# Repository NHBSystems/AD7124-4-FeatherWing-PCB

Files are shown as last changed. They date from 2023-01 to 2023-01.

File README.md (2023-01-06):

# AD7124-4 24bit Analog Sensor FeatherWing Design Files

This is a new Feather compatible board for reading precision analog sensors like load cells, thermocouples, and strain gauges. It uses the AD7124-4, a 4 channel, 24 bit, differential ADC (Can also be configured as 7 single ended channels). Like the [6 Channel 24 bit Featherwing](https://github.com/NHBSystems/6Ch-24bit-FeatherWing-PCB) this board is designed for lower power, monitoring type applications, however it can also be configured for significantly higher sampling rates than the AD7794. The board also includes a low pass anti-aliasing filter on the inputs, a 5th input pin for a shield wire connection, and software enabled excitation voltage without using an additional pin.

**Specifications**

- RMS noise down to 23 nV at 9.4 SPS
- Low power operation with 3 conversion power modes
- Power-down current of 5 μA maximum (AD7124 chip)
- Low noise, programmable gain instrumentation amplifier (1 to 128)
- Band gap reference with 10 ppm/°C drift typical
- Simultaneous 50 Hz/60 Hz rejection at 25 SPS
- Update rate: Up to 19200 sps (per datasheet for single channel)
- 4 differential analog inputs, (or 7 single ended)
- Independent configuration of each channel
- Low pass anti-aliasing filter on inputs
- 5 pin connections with excitation, ground, and shield for each channel
- Shield can be tied to chassis or to ground (trace jumper on bottom)
- On board 2.5v LDO controlled in software without needing additional pin
- Software enabled bias voltage on all channels (for reading thermocouples)

This board can be purchased assembled here: [24 bit Analog Sensor FeatherWing](https://www.tindie.com/products/24680/)



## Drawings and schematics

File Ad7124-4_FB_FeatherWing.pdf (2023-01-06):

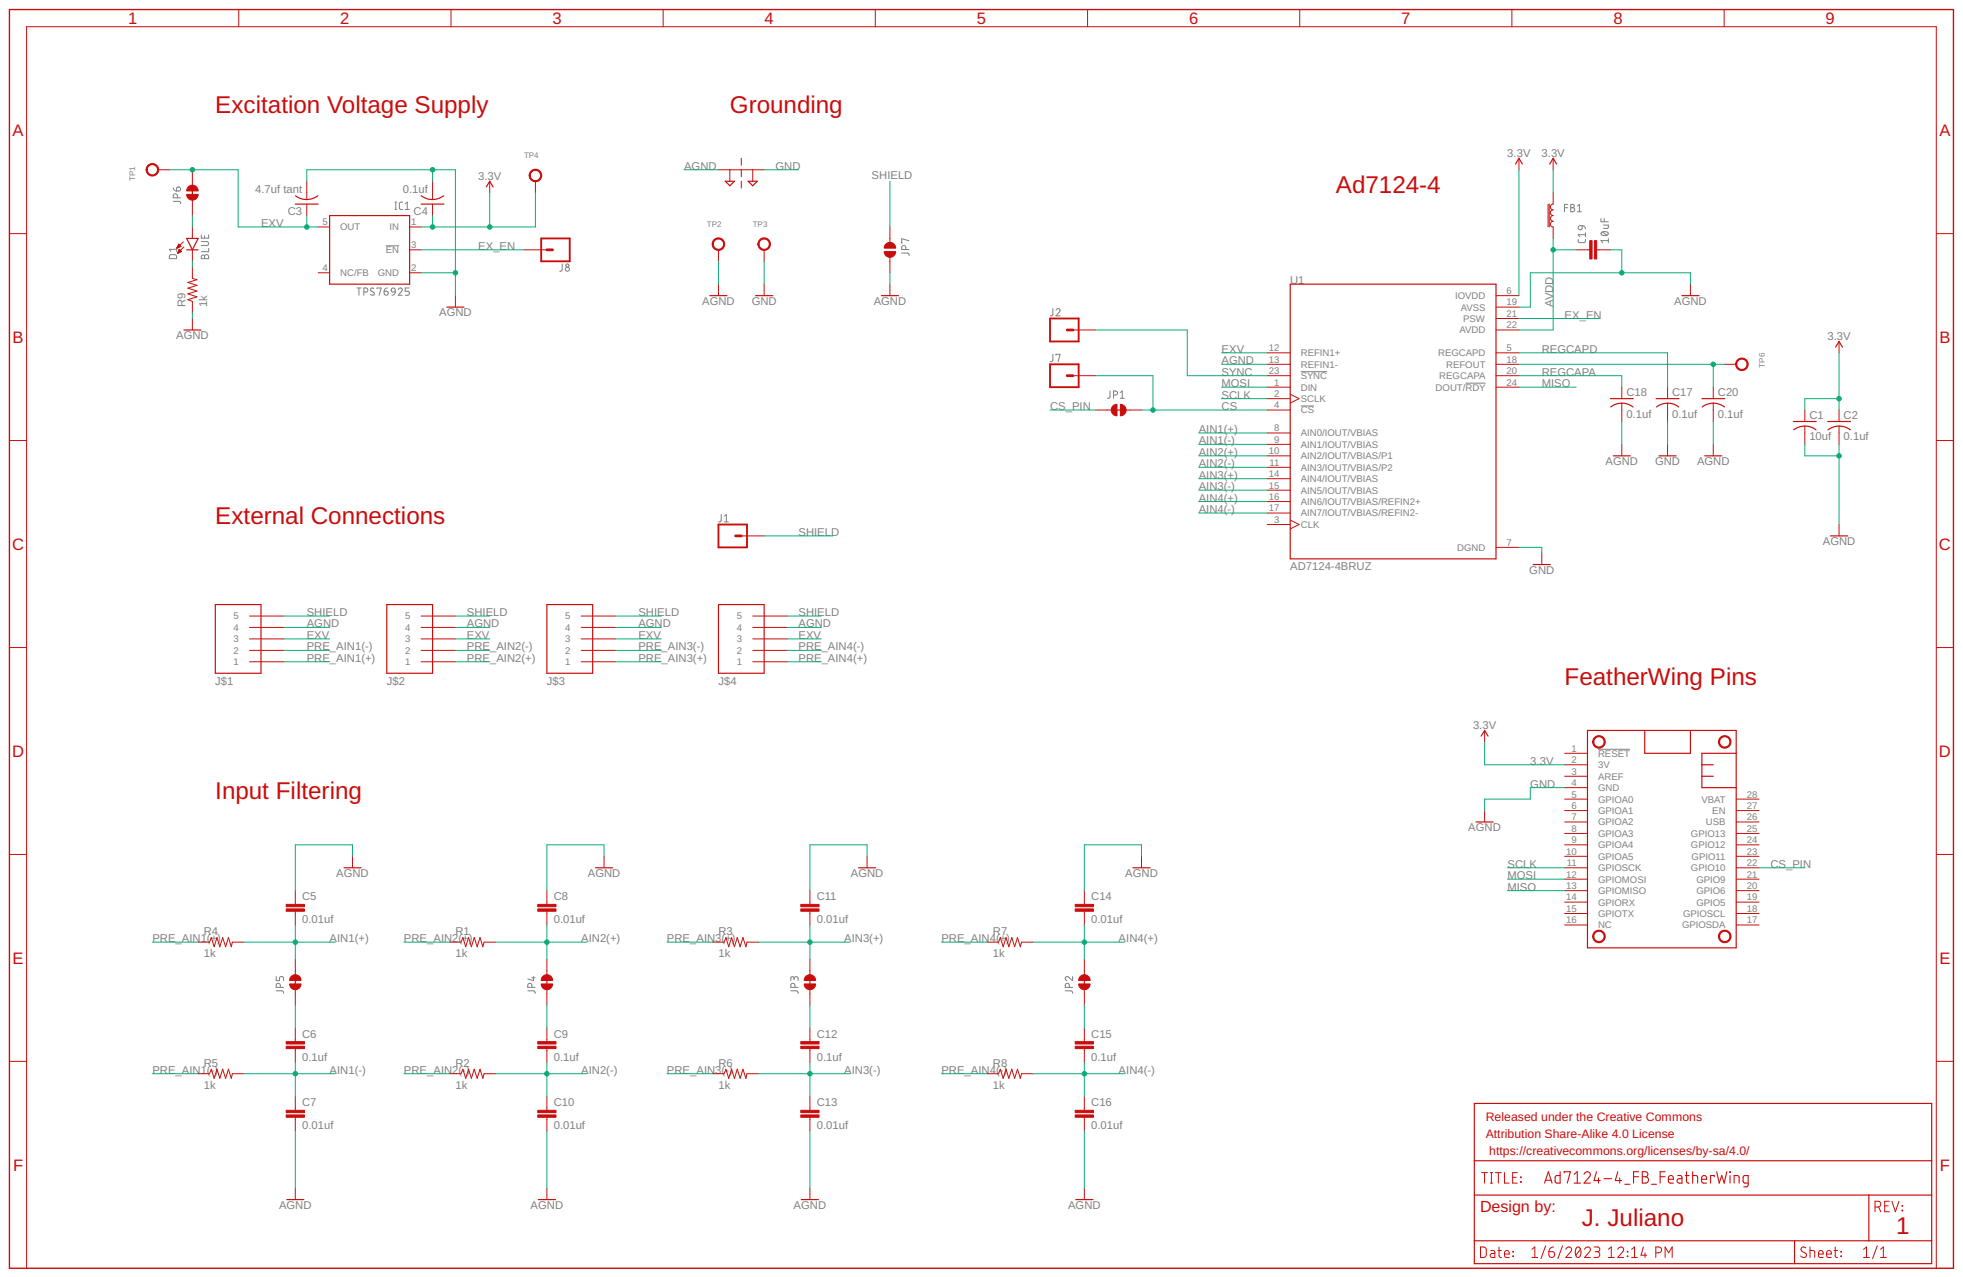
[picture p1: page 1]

Released under the Creative Commons Attribution Share-Alike 4.0 License

https://creativecommons.org/licenses/by-sa/4.0/

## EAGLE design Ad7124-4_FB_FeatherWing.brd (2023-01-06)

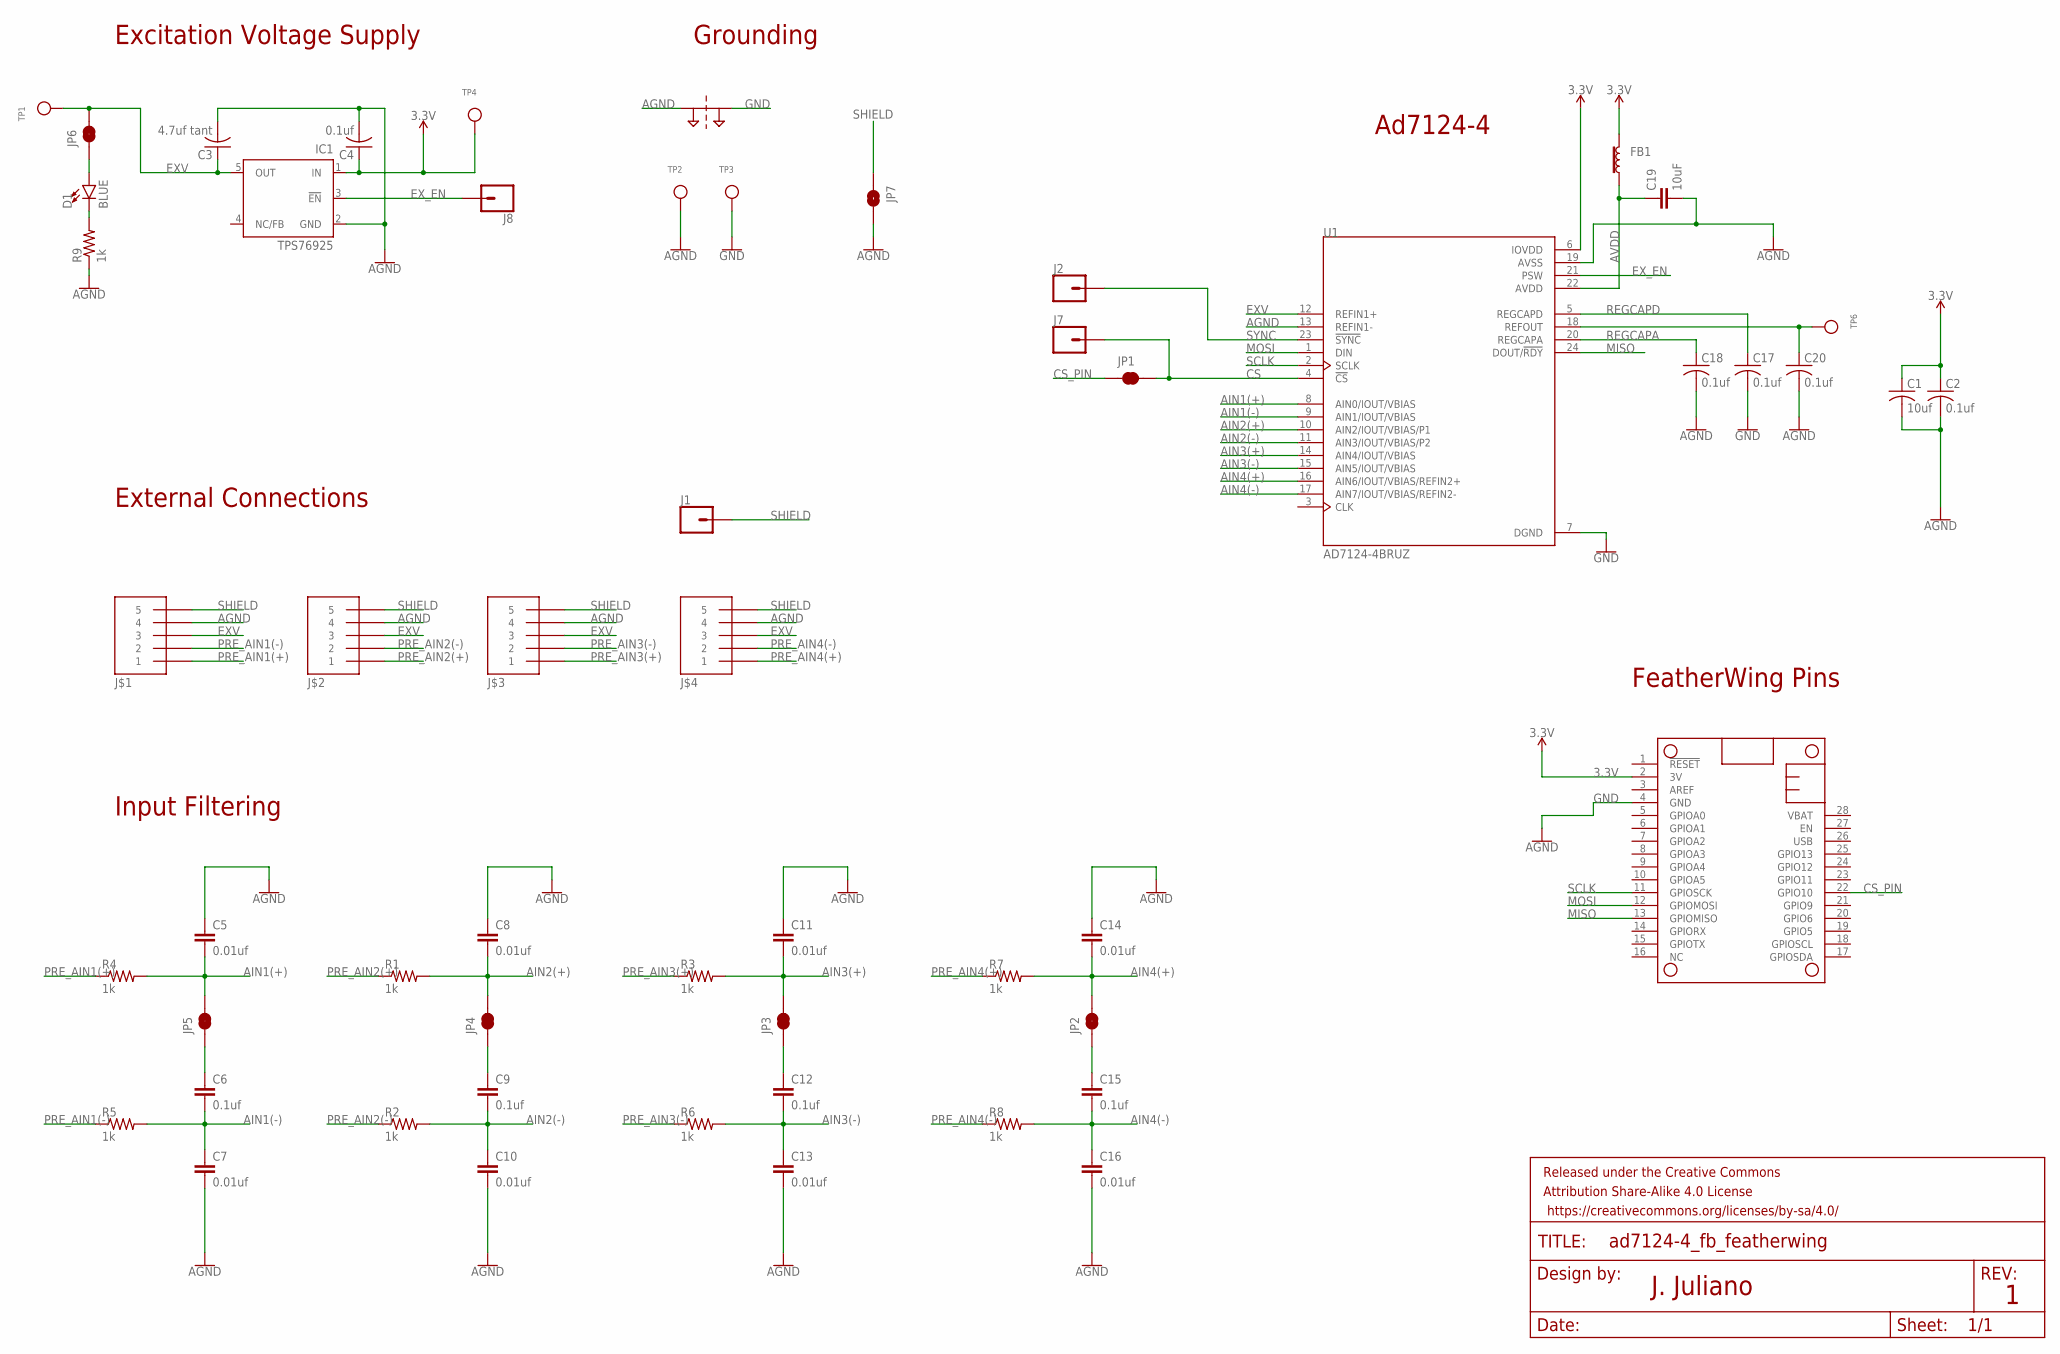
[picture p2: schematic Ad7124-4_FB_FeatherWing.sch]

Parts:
C1: 10uf; C0603
C2, C4, C6, C9, C12, C15, C17, C18, C20: 0.1uf; C0603
C3: 4.7uf tant; C0603
C5, C7, C8, C10, C11, C13, C14, C16: 0.01uf; C0603
C19: 10uF; 0603
D1: BLUE; LED-0603
FB1: FERRITE_BEAD-0603; 0603
FRAME2: FRAME-LETTER; CREATIVE_COMMONS
IC1: TPS76925; SOT23-DBV
J1, J2, J7, J8: CONN_01PTH_NO_SILK_YES_STOP; 1X01_NO_SILK
J$1, J$2, J$3, J$4: CON_PTSM_SOCKET-5-PTH-VERT
JP1, JP2, JP3, JP4, JP5, JP6: JUMPER-SMT_2_NC_TRACE_NO-SILK; SMT-JUMPER_2_NC_TRACE_NO-SILK
JP7: JUMPER-SMT_2_NO_NO-SILK; SMT-JUMPER_2_NO_NO-SILK
MS1: FEATHERWING_NODIM; FEATHERWING_DIM
R1, R2, R3, R4, R5, R6, R7, R8, R9: 1k; R0603
SUPPLY6: 2PT_GND_TIE
TP1, TP2, TP3, TP4, TP6: TESTPOINTROUND1MM; TESTPOINT_ROUND_1MM
U1: AD7124-4BRUZ; SOP65P640X120-24N

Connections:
3.3V: C1.1, C2.1, C4.1, FB1.2, IC1.1 (IN), MS1.2 (3V), TP4.P$1, U1.6 (IOVDD)
AGND: C5.1, C7.2, C8.1, C10.2, C11.1, C13.2, C14.1, C16.2, C18.2, C19.2, C20.2, J$1.P$4 (4), J$2.P$4 (4), J$3.P$4 (4), J$4.P$4 (4), JP7.2, R9.1, SUPPLY6.P$1, TP2.P$1, U1.13 (REFIN1-), U1.19 (AVSS)
AIN1(+): C5.2, JP5.2, R4.2, U1.8 (AIN0/IOUT/VBIAS)
AIN1(-): C6.2, C7.1, R5.2, U1.9 (AIN1/IOUT/VBIAS)
AIN2(+): C8.2, JP4.2, R1.2, U1.10 (AIN2/IOUT/VBIAS/P1)
AIN2(-): C9.2, C10.1, R2.2, U1.11 (AIN3/IOUT/VBIAS/P2)
AIN3(+): C11.2, JP3.2, R3.2, U1.14 (AIN4/IOUT/VBIAS)
AIN3(-): C12.2, C13.1, R6.2, U1.15 (AIN5/IOUT/VBIAS)
AIN4(+): C14.2, JP2.2, R7.2, U1.16 (AIN6/IOUT/VBIAS/REFIN2+)
AIN4(-): C15.2, C16.1, R8.2, U1.17 (AIN7/IOUT/VBIAS/REFIN2-)
AVDD: C19.1, FB1.1, U1.22 (AVDD)
CS: J7.1, JP1.2, U1.4 (!CS)
CS_PIN: JP1.1, MS1.22 (GPIO10)
EXV: C3.1, IC1.5 (OUT), J$1.P$3 (3), J$2.P$3 (3), J$3.P$3 (3), J$4.P$3 (3), JP6.2, TP1.P$1, U1.12 (REFIN1+)
EX_EN: IC1.3 (!EN), J8.1, U1.21 (PSW)
GND: C1.2, C2.2, C3.2, C4.2, C17.2, IC1.2 (GND), MS1.4 (GND), SUPPLY6.P$2, TP3.P$1, U1.7 (DGND)
MISO: MS1.13 (GPIOMISO), U1.24 (DOUT/!RDY)
MOSI: MS1.12 (GPIOMOSI), U1.1 (DIN)
unnamed: D1.A, JP6.1
unnamed: C15.1, JP2.1
unnamed: C12.1, JP3.1
unnamed: D1.C, R9.2
unnamed: C9.1, JP4.1
unnamed: C6.1, JP5.1
unnamed: C20.1, TP6.P$1, U1.18 (REFOUT)
PRE_AIN1(+): J$1.P$1 (1), R4.1
PRE_AIN1(-): J$1.P$2 (2), R5.1
PRE_AIN2(+): J$2.P$1 (1), R1.1
PRE_AIN2(-): J$2.P$2 (2), R2.1
PRE_AIN3(+): J$3.P$1 (1), R3.1
PRE_AIN3(-): J$3.P$2 (2), R6.1
PRE_AIN4(+): J$4.P$1 (1), R7.1
PRE_AIN4(-): J$4.P$2 (2), R8.1
REGCAPA: C18.1, U1.20 (REGCAPA)
REGCAPD: C17.1, U1.5 (REGCAPD)
SCLK: MS1.11 (GPIOSCK), U1.2 (SCLK)
SHIELD: J1.1, J$1.P$5 (5), J$2.P$5 (5), J$3.P$5 (5), J$4.P$5 (5), JP7.1
SYNC: J2.1, U1.23 (!SYNC)

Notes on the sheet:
Excitation Voltage Supply
FeatherWing Pins
Ad7124-4
External Connections
Input Filtering
J. Juliano
Grounding

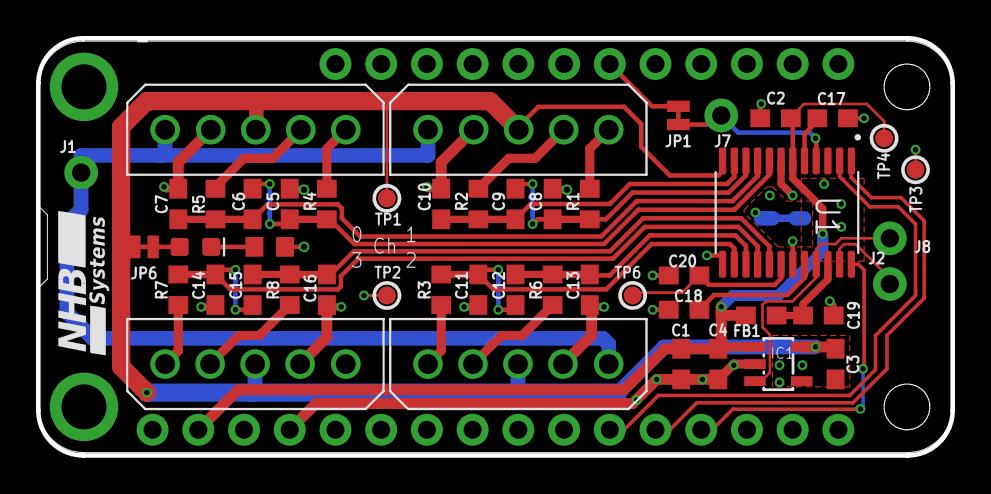
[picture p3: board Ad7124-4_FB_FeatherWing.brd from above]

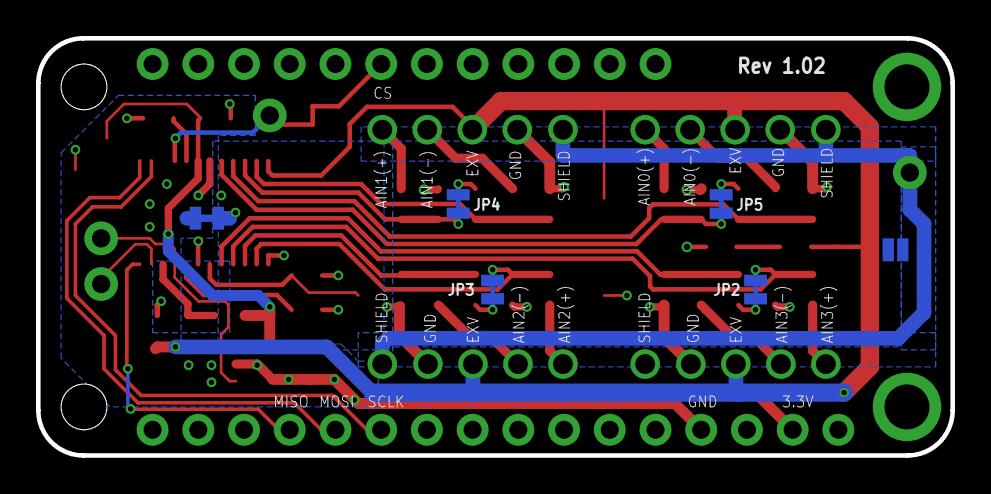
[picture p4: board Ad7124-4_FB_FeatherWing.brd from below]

Board: 2 copper layers, 50.8 x 23.2 mm, 57 parts (6 on the bottom side), 38 nets.

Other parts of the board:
U$5: NHB_COMPACT_LOGO_SMALL

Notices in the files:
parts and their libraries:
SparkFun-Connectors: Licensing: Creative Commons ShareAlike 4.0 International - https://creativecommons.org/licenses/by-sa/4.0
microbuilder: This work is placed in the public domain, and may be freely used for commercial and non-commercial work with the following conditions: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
